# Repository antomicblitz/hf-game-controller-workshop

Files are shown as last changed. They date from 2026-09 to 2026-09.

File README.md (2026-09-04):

# HF Game Controller Workshop

Build a browser game, customize its six-button controller case, and wire the
working USB controller. No previous programming experience is required.

Use **macOS**, or **Ubuntu in WSL2** on Windows. PrusaSlicer is provided
separately for the workshop.

## 1. Set up OpenCode

Follow [Setup](docs/01-setup.md), then run:

```console
make setup
make connect
make doctor
```

## 2. Build your game and view STLs

Follow [Game and STL viewer](docs/02-game-and-stl-viewer.md).

```console
make agent
make web
```

## 3. Customize and print the case

Follow [Case editor and printing](docs/03-case-editor-and-print.md).

```console
make editor
```

Open the printed local URL. Download both STLs when finished. Press **Ctrl+C**
to stop the editor, then slice the files in PrusaSlicer and save the G-code to
an SD card.

## 4. Wire the controller

Follow [Wiring and firmware](docs/04-wiring-and-firmware.md).

If something does not work, run `make doctor` and show the result to Antonio.

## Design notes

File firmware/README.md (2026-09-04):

# Controller firmware

This copy-ready firmware is for the Adafruit Feather nRF52840 Sense (PID 4516).

- CircuitPython: 10.3.0 en_US
- Board ID: `nRF52840-Feather-Sense`
- [Download the validated UF2](https://downloads.circuitpython.org/bin/feather_bluefruit_sense/en_US/adafruit-circuitpython-feather_bluefruit_sense-en_US-10.3.0.uf2)
- SHA-256: `61c9d670d0ed5706af0dbf1fe3b180c43697094f0cf2b1c40f651735e4af7556`

After installing the UF2, copy the **contents** of `CIRCUITPY/` to the root of
the board's `CIRCUITPY` drive. Do not copy the outer folder itself.

See [Wiring and firmware](../docs/04-wiring-and-firmware.md) for the complete
student procedure.

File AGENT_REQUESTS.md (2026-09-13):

# Agent requests

Unresolved decisions that need a human, not an agent.

- Provide the public link for the **Super Maga Bros** reference game so
  `docs/02-game-and-stl-viewer.md` can mention it (see section "Controller
  contract").
- Decide CI scope for the sandbox-dependent maintainer suite. GitHub-hosted
  ubuntu runners cannot complete four `tests/test_llm_case_customization.py`
  cases that need a real CAD sandbox, so CI now runs `make validate` only
  (matching the Makefile's "maintainer-only" design and open PR #2, which
  this supersedes). If CI should run `make maintainer-validate`, that needs
  capability-skip handling around `cadkit.case_execution.sandbox_status()`,
  or a self-hosted runner where bubblewrap works.

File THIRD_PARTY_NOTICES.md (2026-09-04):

# Third-party software

This repository depends on separately licensed open-source packages listed in
`pyproject.toml`. It loads these pinned browser libraries from their public CDN:

- [Three.js](https://github.com/mrdoob/three.js), MIT License, version 0.180.0.
- [model-viewer](https://github.com/google/model-viewer), Apache License 2.0,
  version 3.5.0.

No vendor CAD files, component models, or CircuitPython binaries are copied
into this repository. The firmware guide links to the official Adafruit image.

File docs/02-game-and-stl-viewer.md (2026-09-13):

# 2. Build a game and view STL files

The coding harness starts in **Plan** mode so you can describe an idea before
anything changes.

```console
make agent
```

Try a prompt such as:

> Plan a one-screen game about collecting lost satellites. Make it playable in
> under one minute and use both action buttons.

Review the plan, switch to the **Build** agent, and ask it to implement the
plan. The agent changes only `student-project/` and keeps the project as plain
HTML, CSS, and JavaScript.

Start the local site in another terminal:

```console
make web
```

Open <http://127.0.0.1:8000>. Press **Ctrl+C** in that terminal to stop it.

## Controller contract

Games use `student-project/controller-input.js`, which returns these six names:

| Game input | USB gamepad | Keyboard fallback |
|---|---|---|
| up / down | Y axis, index 1 | Up / Down Arrow |
| left / right | X axis, index 0 | Left / Right Arrow |
| action A | button index 0 | Z |
| action B | button index 1 | X |

Do not assume the controller is gamepad number zero. The supplied adapter finds
a compatible connected controller, handles reconnects, and applies a digital
dead zone. Build game rules against its semantic values instead of reading
`navigator.getGamepads()` again.

**Super Maga Bros** is the in-class reference for a small controller game.
This repository does not copy or depend on its code.

## STL viewer

Choose **STL viewer** on the project home page. It can load the bundled top and
bottom case or an STL selected from your computer. Selected files stay in the
browser and are not uploaded.

Run `make web-check` after changing the game or viewer.

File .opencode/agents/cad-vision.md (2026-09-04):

---
description: Produces one bounded typed case-edit proposal for the visual editor without running coding tools.
mode: primary
# One response is enough: the caller validates the typed proposal and owns all
# source changes.
steps: 1
# --pure disables external plugins, not built-in, custom, or MCP tools. A
# wildcard deny keeps every current and future tool outside this agent.
permission: deny
---

# CAD vision

You are a single-response CAD layout proposer. Follow the complete contract in
the user's message without inspecting or modifying files and without calling
tools. Return only the strict `cadkit.case-edit/1.0` JSON object requested by
the user. Never return Python, Build123d source, Markdown fences, explanations,
progress notes, or questions.

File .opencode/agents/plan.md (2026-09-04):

---
description: Plans a small controller-compatible browser game or STL-viewer change without editing files.
mode: primary
permission:
  edit: deny
  bash: deny
---

# Workshop planner

You are the planning agent for a beginner game-controller workshop. Read
`AGENTS.md`, `docs/02-game-and-stl-viewer.md`, and the existing
`student-project/` files. Ask only questions that block a useful plan. Produce
the smallest playable vertical slice, list the exact files to change, and end
with checks for Arrow/Z/X keyboard input, the exact-six USB controller, and the
local browser experience. Do not edit files or propose new frameworks,
services, package managers, or controller mappings.

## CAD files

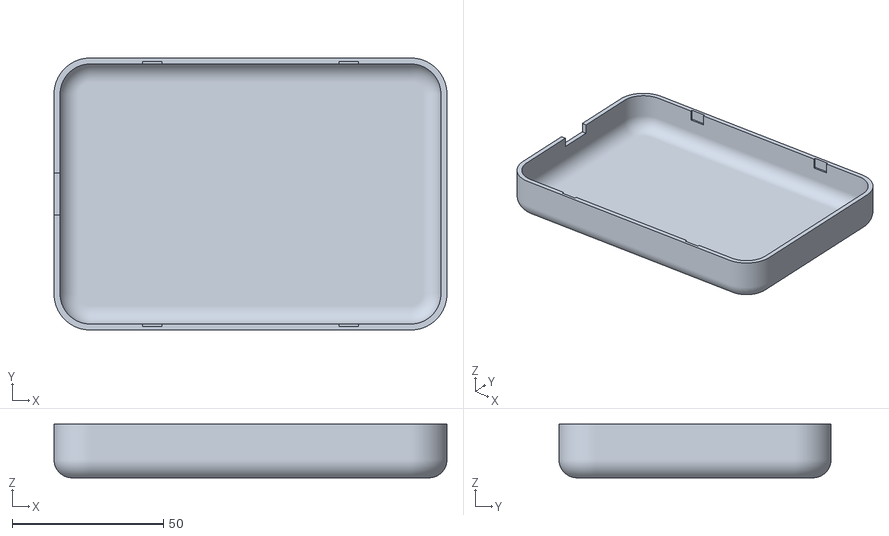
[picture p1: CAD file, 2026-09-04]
controller/default-stl/case-bottom.stl
130.0 x 90.0 x 17.8

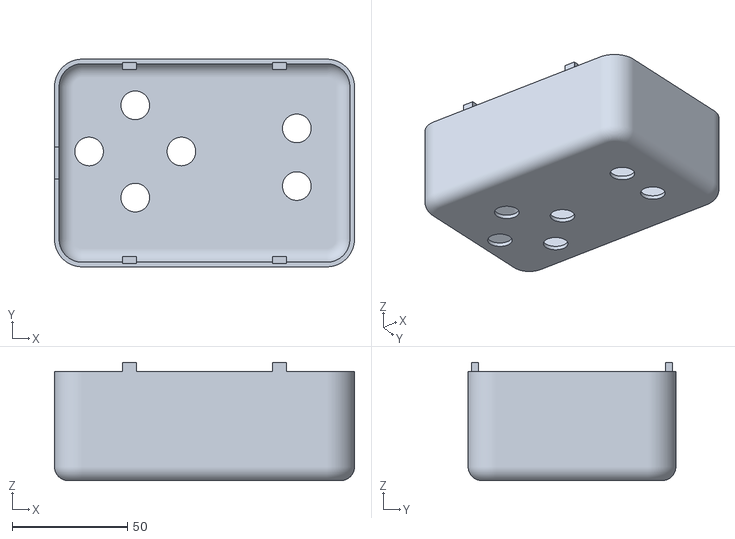
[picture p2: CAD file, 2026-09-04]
student-project/assets/case-top.stl
130.0 x 90.0 x 51.2

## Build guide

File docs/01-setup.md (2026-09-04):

# 1. Setup

The case editor runs locally on your computer. Internet access is used only for
OpenCode Zen and the browser's pinned 3D-viewer libraries.

## macOS

1. Open **Terminal**.
2. If `git`, `make`, or Python are missing, install Apple's command-line tools
   and Homebrew, then run:

   ```console
   xcode-select --install
   brew install python@3.12 cairo
   ```

3. Install OpenCode with its official installer:

   ```console
   curl -fsSL https://opencode.ai/install | bash
   ```

## Windows with WSL2

1. Open **PowerShell as Administrator**, run this once, then restart Windows:

   ```powershell
   wsl --install -d Ubuntu
   ```

2. Open **Ubuntu**, then install the prerequisites:

   ```console
   sudo apt update
   sudo apt install -y git make python3 python3-venv python3-pip bubblewrap libseccomp2 libcairo2
   curl -fsSL https://opencode.ai/install | bash
   ```

Run all later `make` commands in Ubuntu, not PowerShell. Your normal Windows
browser can open the printed `127.0.0.1` URLs.

## Get the workshop repository

```console
git clone https://github.com/antomicblitz/hf-game-controller-workshop.git
cd hf-game-controller-workshop
make setup
```

## Add the workshop Zen key

Antonio supplies the temporary key privately. Run:

```console
make connect
```

Choose **OpenCode Zen** if asked and paste the key only into OpenCode's hidden
credential prompt. Never paste it into a file, chat prompt, browser form,
design brief, screenshot, or Git commit.

The project already selects the tested workshop model. Check everything with:

```console
make doctor
```

Every line should begin with `OK`. After the workshop, remove the temporary
credential with `make disconnect` and choose OpenCode Zen.

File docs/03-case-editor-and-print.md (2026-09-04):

# 3. Customize and print the case

The approved default case is 130 x 90 x 65 mm with four directional buttons on
the left and action A/B on the right. The editor permits bounded shape changes
and validated button moves while protecting the electronics, USB opening,
shell, and snap-fit regions.

## Start the editor

```console
make doctor
make editor
```

Open the `http://127.0.0.1:...` URL printed in the terminal. The editor is
available only on your computer.

1. Use **2D Layout** to drag a permitted button.
2. Use **3D Review** to orbit and inspect the assembled controller.
3. Describe a case-shape change, then press **Send**.
4. Compare **Before** and **After**.
5. Download `case-top.stl` and `case-bottom.stl`.

Invalid or unprintable changes are rejected. **Reset design** returns to the
approved rounded case. Press **Ctrl+C** in the terminal to stop the editor.

If customization is unavailable, use the known-good files in
`controller/default-stl/`.

## PrusaSlicer and SD card

PrusaSlicer is already installed for the course; this repository does not
install or control it.

1. Open both STLs in PrusaSlicer.
2. Select the preset for the assigned printer, a **0.4 mm nozzle**, and **PLA**.
3. Keep the supplied flat orientation. Confirm each half touches the build
   plate correctly.
4. Use **0.28 mm** layers, **3 perimeters**, **20% gyroid infill**, and
   **supports off**, unless Antonio gives your team a different preset.
5. Slice and inspect the complete layer preview before exporting.
6. Export G-code to the SD card, safely eject it, insert it in the assigned
   printer, and start the file from the printer controls.

Do not send files directly to a printer from this repository.

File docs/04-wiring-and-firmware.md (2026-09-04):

# 4. Wiring and firmware

Each controller has four normally-open directional buttons and two
normally-open action buttons. Read the complete procedure before connecting
USB power.

Exact-six wiring diagram

## Wiring map

| Control | Feather pin | Browser result |
|---|---|---|
| Up | D5 | Y negative |
| Down | D6 | Y positive |
| Right | D9 | X positive |
| Left | D10 | X negative |
| Action A | D11 | button 0 |
| Action B | D12 | button 1 |

For every button, connect one terminal to its signal pin and the other terminal
to the common blue ground rail. Bridge Feather **GND** to that rail. The red
rail is unused. USB powers the Feather; no separate power wire is needed.

With the Feather USB connector facing left, the upper breadboard positions are:

```text
9 D12 · 10 D11 · 11 D10 · 12 D9 · 13 D6 · 14 D5
```

Lower position 4 is GND and connects to the blue rail. Upper and lower rows on
opposite sides of the breadboard centre trench are not connected.

## Copy the validated firmware

The firmware is for the **Adafruit Feather nRF52840 Sense, PID 4516** and the
validated CircuitPython 10.3.0 UF2 linked in `firmware/README.md`.

1. Disconnect the button wiring from USB power.
2. Double-press Feather Reset to open the `FTHR840BOOT` drive.
3. Drag the validated CircuitPython UF2 onto that drive. It reconnects as
   `CIRCUITPY`.
4. Back up any existing files on `CIRCUITPY`.
5. Copy the **contents** of `firmware/CIRCUITPY/` to the root of the drive.
6. Safely eject and reconnect the Feather.

On Windows, do these drive-copy steps in File Explorer, not inside WSL2.

## Wire and test

1. Keep USB disconnected while wiring.
2. Label all six signal leads before connecting them.
3. Use insulated alligator/Dupont leads or solid breadboard ends. Never put
   loose stranded wire into the breadboard.
4. Insulate exposed joints and add strain relief.
5. Check continuity from each pin to its button and from all six returns to GND.
6. Confirm released signals are not shorted to GND or to one another.
7. Connect USB and open the included game starter. Test every direction and
   both action buttons separately.
8. Route wires away from the buttons, USB opening, and snap-fit edges before
   closing the case. Bond the breadboard assembly to the inside bottom surface
   with its factory adhesive.

Disconnect USB immediately if the board becomes hot, repeatedly disconnects,
or reports a short circuit.

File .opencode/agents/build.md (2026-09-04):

---
description: Builds the planned beginner browser game or STL-viewer change inside student-project.
mode: primary
---

# Workshop builder

You are the build agent for a beginner game-controller workshop. Read
`AGENTS.md`, `docs/02-game-and-stl-viewer.md`, and the approved plan. Implement
the smallest playable change under `student-project/` only. Reuse
`controller-input.js`; preserve keyboard and exact-six controller support. Use
plain HTML, CSS, and JavaScript with no installation or build step. Keep local
files local, never request credentials, and run `make web-check` before you
finish. Explain the result in plain language.

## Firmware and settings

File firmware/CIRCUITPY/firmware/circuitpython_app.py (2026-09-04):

"""CircuitPython runtime for the active exact-six GPIO controller.

Only this module imports CircuitPython-only modules.  The runtime has six
normally-open inputs, all configured with internal pull-ups, and publishes a
four-byte HID report whenever the debounced semantic state changes.
"""

from .debounce import Debouncer
from .gpio_map import CONTROL_IDS, GPIO_NAMES_BY_CONTROL
from .hid_report import compute_hid_report
from .polling import POLL_PERIOD_S, read_control_states
from .serialization import HID_REPORT_BYTES, serialize_hid_report

MODE_NORMAL = "NORMAL"
HID_REPORT_ID = 0


class _DigitalPin:
    value: bool
    direction: object
    pull: object


class _DigitalioModule:
    class Direction:
        INPUT: object

    class Pull:
        UP: object

    def DigitalInOut(self, pin: object) -> _DigitalPin: ...


class _BoardModule:
    pass


class _UsbDevice:
    report_descriptor: bytes
    usage_page: int
    usage: int
    report_ids: "tuple[int, ...]"
    in_report_lengths: "tuple[int, ...]"
    out_report_lengths: "tuple[int, ...]"

    def send_report(self, payload: bytes) -> None: ...


class _DeviceCollection:
    def __len__(self) -> int: ...

    def __getitem__(self, index: int) -> _UsbDevice: ...


class _UsbHidModule:
    devices: _DeviceCollection

    def Device(self, **kwargs: object) -> _UsbDevice: ...

    def enable(self, devices: object) -> None: ...


class _PublishState:
    pins: "list[object]"
    debouncers: "list[Debouncer]"
    dt_s: float
    last_payload: object

    def __init__(self, pins: "list[object]") -> None:
        self.pins = pins
        self.debouncers = [Debouncer() for _ in pins]
        self.dt_s = POLL_PERIOD_S
        self.last_payload = None


class FirmwareError(RuntimeError):
    """Raised when CircuitPython libraries, USB setup, or wiring is invalid."""


def _import_circuitpython_libs():
    """Import the CircuitPython core modules required by the active path."""
    try:
        import board  # pyright: ignore[reportMissingImports]
        import digitalio  # pyright: ignore[reportMissingImports]
        import usb_hid  # pyright: ignore[reportMissingImports]
    except ImportError as exc:
        raise FirmwareError(
            "CircuitPython standard library import failed. "
            "Verify the firmware is running on an Adafruit Feather nRF52840 Sense "
            "(PID 4516): " + str(exc)
        ) from exc

    board_mod: _BoardModule = board  # pyright: ignore[reportAssignmentType]
    digitalio_mod: _DigitalioModule = digitalio  # pyright: ignore[reportAssignmentType]
    usb_hid_mod: _UsbHidModule = usb_hid  # pyright: ignore[reportAssignmentType]
    return board_mod, digitalio_mod, usb_hid_mod


def build_gpio_pins(
    digitalio_mod: object, board_mod: object, gpio_names: "tuple[str, ...]"
) -> "list[object]":
    """Configure the exact six GPIO inputs with internal pull-ups."""
    typed_digitalio: _DigitalioModule = digitalio_mod  # pyright: ignore[reportAssignmentType]
    pins: "list[object]" = []  # noqa: UP037 — avoid PEP 585 evaluation on-device
    if gpio_names != GPIO_NAMES_BY_CONTROL:
        raise FirmwareError("GPIO map does not match the exact-six contract: " + repr(gpio_names))
    for name in gpio_names:
        pin = typed_digitalio.DigitalInOut(getattr(board_mod, name))
        pin.direction = typed_digitalio.Direction.INPUT
        pin.pull = typed_digitalio.Pull.UP
        pins.append(pin)
    return pins


def resolve_mode(mode: str) -> str:
    """Accept only the production runtime mode."""
    if mode == MODE_NORMAL:
        return mode
    raise FirmwareError(f"unknown HF_FW_MODE {mode!r}; expected {MODE_NORMAL!r}")


def _publish_report(state: _PublishState, gamepad: object) -> bytes:
    """Sample, debounce, and publish one exact-six HID state."""
    typed_gamepad: _UsbDevice = gamepad  # pyright: ignore[reportAssignmentType]
    sampled_states = read_control_states(state.pins)
    stable_states: "dict[str, bool]" = {}  # noqa: UP037 — device-safe annotation
    for index, control_id in enumerate(CONTROL_IDS):
        stable_states[control_id] = state.debouncers[index].update(
            sampled_states[control_id], state.dt_s
        )

    payload = serialize_hid_report(compute_hid_report(stable_states))
    if payload != state.last_payload:
        typed_gamepad.send_report(payload)
        state.last_payload = payload
    return payload


def _run_normal_hid_loop() -> object:
    """Run the production GPIO → debounce → HID loop at 100 Hz."""
    from .scheduler import DeadlineScheduler

    board_mod, digitalio_mod, usb_hid_mod = _import_circuitpython_libs()
    pins = build_gpio_pins(digitalio_mod, board_mod, GPIO_NAMES_BY_CONTROL)
    if len(usb_hid_mod.devices) != 1:
        raise FirmwareError(
            "expected exactly one usb_hid device enabled by boot.py, found "
            + str(len(usb_hid_mod.devices))
        )
    gamepad = usb_hid_mod.devices[0]
    state = _PublishState(pins)

    def on_tick(dt_s: float) -> None:
        state.dt_s = dt_s
        _publish_report(state, gamepad)

    scheduler = DeadlineScheduler(POLL_PERIOD_S, on_tick)
    while True:
        scheduler.tick()


def main(mode: str = MODE_NORMAL) -> object:
    """Validate ``mode`` and start the production loop."""
    resolve_mode(mode)
    return _run_normal_hid_loop()


def make_gamepad_device(usb_hid_mod: object) -> _UsbDevice:
    """Construct the four-byte USB HID gamepad descriptor."""
    typed_usb_hid: _UsbHidModule = usb_hid_mod  # pyright: ignore[reportAssignmentType]
    try:
        return typed_usb_hid.Device(
            report_descriptor=bytes(_GAMEPAD_REPORT_DESCRIPTOR),
            usage_page=0x01,
            usage=0x05,
            report_ids=(HID_REPORT_ID,),
            in_report_lengths=(HID_REPORT_BYTES,),
            out_report_lengths=(0,),
        )
    except (OSError, ValueError) as exc:
        raise FirmwareError("Could not construct the USB HID gamepad device: " + str(exc)) from exc


def enable_hid_device(usb_hid_mod: object, device: object) -> None:
    """Enable the gamepad before USB enumeration completes."""
    typed_usb_hid: _UsbHidModule = usb_hid_mod  # pyright: ignore[reportAssignmentType]
    try:
        typed_usb_hid.enable((device,))
    except (OSError, ValueError) as exc:
        raise FirmwareError("usb_hid.enable() rejected the gamepad device: " + str(exc)) from exc
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

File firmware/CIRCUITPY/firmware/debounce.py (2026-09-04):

"""Software debouncing — settle-time filter for the GPIO inputs.

Why a debouncer in the firmware
===============================

Mechanical pushbuttons bounce: a single press can produce a brief
train of make/break edges over 1–10 ms before settling. The USB
HID stack sees every transition, so without debouncing one press
becomes several HID reports. We hold a press candidate for a
minimum settle window before publishing the new state.

Pure state machine
==================

The debouncer is a tiny Mealy machine with no hardware imports.
It avoids ``dataclasses`` so it imports cleanly on CircuitPython
8.x without requiring the optional ``dataclasses`` stdlib module.
"""

# Settle window — chosen so a single button bounce (≤ 10 ms typical,
# ≤ 25 ms worst case for PBS-33B) cannot leak through, while still
# feeling responsive to a human finger (~ 80–150 ms typical press).
DEBOUNCE_SETTLE_S = 0.020  # 20 ms


class Debouncer:
    """Settle-time debouncer.

    State diagram::

        raw == candidate          → no change
        raw != candidate          → candidate = raw, candidate_s = dt
        raw == candidate (later)  → candidate_s += dt (extends settle)
        candidate_s >= settle_s
        AND candidate != last_stable → publish candidate

    ``update(raw, dt_s)`` returns the latest **stable** state. The
    internal candidate is only published once it has survived the
    settle window. Callers should poll at the fixed 10 ms production
    period and pass ``dt_s`` as that period.
    """

    settle_s: float
    last_stable: bool
    candidate: bool
    candidate_age_s: float

    def __init__(self, settle_s: float = DEBOUNCE_SETTLE_S) -> None:
        if settle_s <= 0:
            raise ValueError(f"settle_s must be positive, got {settle_s!r}")
        self.settle_s = settle_s
        self.last_stable = False
        self.candidate = False
        self.candidate_age_s = 0.0

    def reset(self, initial: bool = False) -> None:
        """Reset internal state; useful between self-test cases."""
        self.last_stable = initial
        self.candidate = initial
        self.candidate_age_s = 0.0

    def update(self, raw: bool, dt_s: float) -> bool:
        """Advance the debouncer by ``dt_s`` seconds with a new raw sample.

        Returns the latest **stable** state. Callers compare against
        the previous return value to detect the rising/falling edge
        they should publish.
        """
        if dt_s < 0:
            raise ValueError(f"dt_s must be non-negative, got {dt_s!r}")

        if raw == self.candidate:
            # Sample matches the current candidate — extend the
            # settle window.
            self.candidate_age_s = self.candidate_age_s + dt_s
        else:
            # raw disagrees with the candidate — start a fresh
            # settle window with the new sample.
            self.candidate = raw
            self.candidate_age_s = dt_s

        if self.candidate_age_s >= self.settle_s and self.candidate != self.last_stable:
            self.last_stable = self.candidate
            self.candidate_age_s = 0.0
        return self.last_stable

    def age_one_tick(self, dt_s: float) -> bool:
        """Advance the settle clock without changing the raw sample.

        Useful in the main loop where you may have already polled
        several inputs and want to give the candidate time to mature
        without rewriting it. Returns the latest stable state.
        """
        if self.candidate_age_s >= self.settle_s:
            return self.last_stable
        self.candidate_age_s = self.candidate_age_s + dt_s
        if self.candidate_age_s >= self.settle_s and self.candidate != self.last_stable:
            self.last_stable = self.candidate
            self.candidate_age_s = 0.0
        return self.last_stable


__all__ = ["DEBOUNCE_SETTLE_S", "Debouncer"]

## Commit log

2026-09-04 feat: add public controller workshop kit
    [case-bottom.stl, case-top.stl]
2026-09-04 fix: keep student validation fast
    [test_firmware_deploy.py]
2026-09-13 chore: remove unused pytest marker filters and stale coverage omit
    The slow/hardware/network markers were declared and deselected but no
    test ever used them; the fast gate excludes heavy CAD files by file
    list. Coverage also omitted tools/cadkit/export.py, which no longer
    exists. Collection count is unchanged (604 tests).
2026-09-13 docs: remove references to nonexistent PLAN.md and track game link decision
    The PLAN.md 'durable contract' cited in the agent and editor package
    headers never existed in this repository, and the milestone-slice
    jargon around it resolves to nothing. The Super Maga Bros public link
    is a human follow-up, so it moves from the student-facing procedure to
    AGENT_REQUESTS.md.
2026-09-13 test: drop HTTPMethod fallback test with its removed shim
    The test asserted the fallback installs http.HTTPMethod for
    interpreters that lacks it. requires-python is >=3.12, so the fallback
    is unreachable and its dedicated test goes with it. Removal evidence:
    zero remaining shim references and tests/test_snapshot.py green without
    it. Scoped: red/green not applicable — the tested capability no longer
    exists.
    [test_snapshot.py]
2026-09-13 refactor: move printer profile templates from agent into cadkit
    cadkit.printers was importing agent.profiles — the core CAD library
    reaching into the application layer, patched over with a sys.path hack.
    The template registry is CAD-side printer data, so it now lives at
    cadkit.printer_templates and the hack is gone. Template strings are
    path-invariant (tools/*/../slice), so profile identities and hashes are
    unchanged. The module header no longer cites a foreign session layout.
2026-09-13 refactor: expose editor scene and revision API for the agent layer
    The agent loop and vision modules reached into editor.server privates
    (_scene_for_case, _editor_revision) via __dict__ lookups. Both functions
    are stable cross-module API, so they are now public and every caller —
    production and tests — uses attribute access. The shadowing local in
    _validate_move became final_revision.
2026-09-13 refactor: move candidate source contract validators into cadkit
    The editor server kept 23 private AST helpers (~385 lines) that prove a
    generated case.py preserved the authoritative geometry contract before
    sandbox execution. They are pure cadkit-domain trust-boundary logic and
    now live in cadkit.case_contract with one public entry point,
    source_contract_error, imported lazily by submit exactly like the other
    heavy cadkit bridges. Error strings are byte-identical; the contract
    tests that pinned them through server.__dict__ now import the public
    home directly.
    [test_snapshot.py]
2026-09-13 fix: run the fast gates in CI, keeping the maintainer suite maintainer-only
    GitHub-hosted runners cannot satisfy four sandbox-dependent
    tests/test_llm_case_customization.py cases in the maintainer coverage run
    (bubblewrap capability probe fails on hosted ubuntu; pre-existing since
    the PR #1 merge, unrelated to this branch). The Makefile already declares
    the full CAD/coverage suite maintainer-only; CI now honors that. Same
    one-line change as open PR #2 — that PR is superseded by this branch.
    Follow-up options are recorded in AGENT_REQUESTS.md.
